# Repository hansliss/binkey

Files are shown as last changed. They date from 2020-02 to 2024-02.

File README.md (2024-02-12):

# binkey
A binary USB keyboard

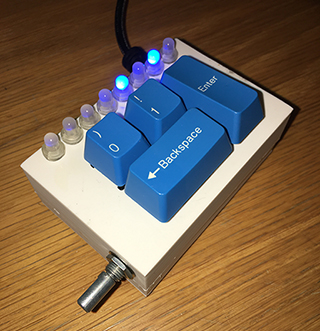
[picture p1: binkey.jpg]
Binkey

Binkey2

You'll need an Arduino Micro or similar, and a nice solution for the USB cable. I cheated and built my own Atmega32U4 PCB and used a scavenged keyboard cable, but you might want to do it differently.

The original box (binkeybox.scad) is designed for Cherry MX keyswitches, with a "0" and "1" key, a vertical straight 2U Enter key and a horizontal straight 2U Backspace key. PLA works fine for this and you probably don't need very high resolution.

Use eight WS2812D-F5 addressable RGB LEDs with the requisite 75Ω resistors on the data lines and 0.1μF capacitors between Vcc and GND (on each LED), and print 16 collars (LEDring.scad) on a resin printer.

I drilled a 7mm hole for the rotary encoder, and I can't be bothered to add this hole to the design.

The new box (binkeybox2.scad) uses only two Cherry keys, a rotary encoder (on the top of the box this time) and a LED strip like Adafruit's 1426.
Notice that the V2 code is tailored for WGRB LEDs. You may need to change that depending on what you use.

For the keyswitches, I used Kailh's hot-swappable sockets, so it's easy to replace the keyswitches without desoldering.

For the rest: Use The Source, Luke!

Oh, and you can find the key codes and modifier codes under "10 Keyboard/Keypad Page (0x07)" in the HID Usage Tables: https://www.usb.org/sites/default/files/documents/hut1_12v2.pdf
For the modifier codes, there's an Excel file that can be used to print out a little lable to glue to the case.

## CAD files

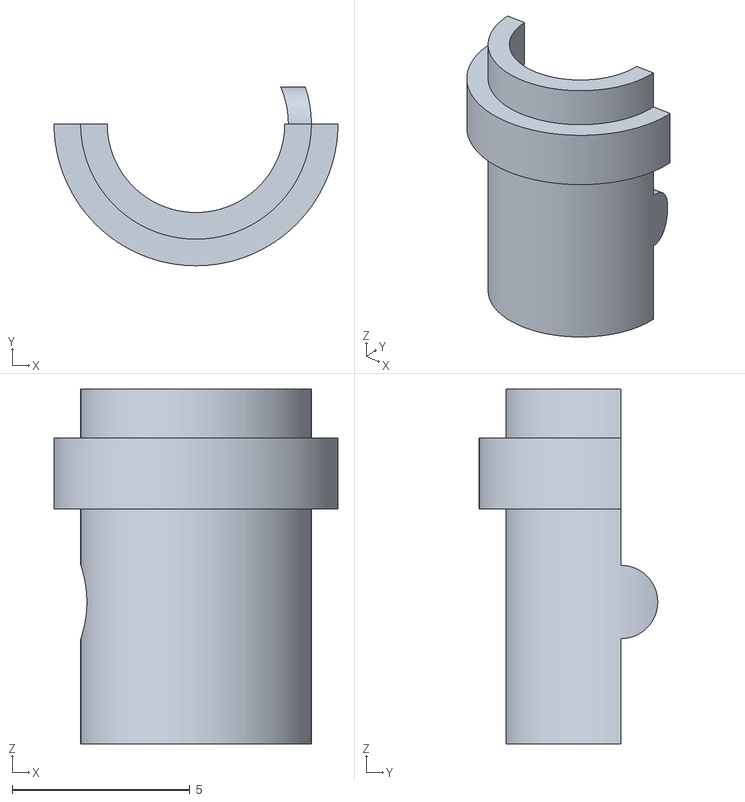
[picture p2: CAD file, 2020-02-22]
LEDring.stl
8.00 x 5.03 x 10.0

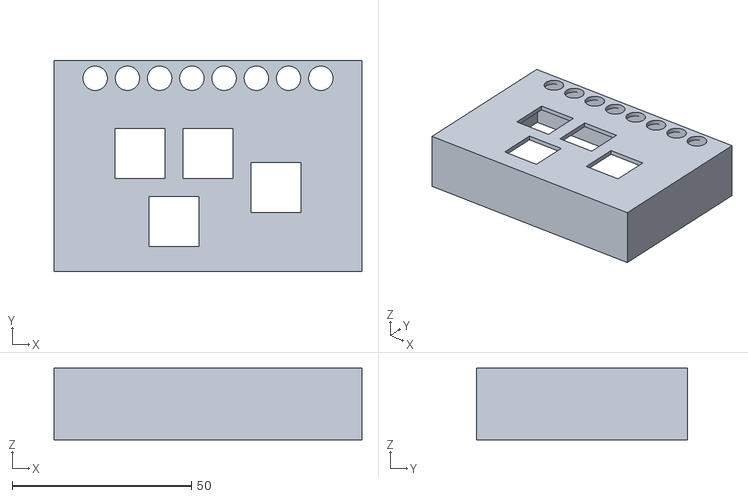
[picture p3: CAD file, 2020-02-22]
BinkeyBoxTop.stl
86.0 x 59.0 x 20.0

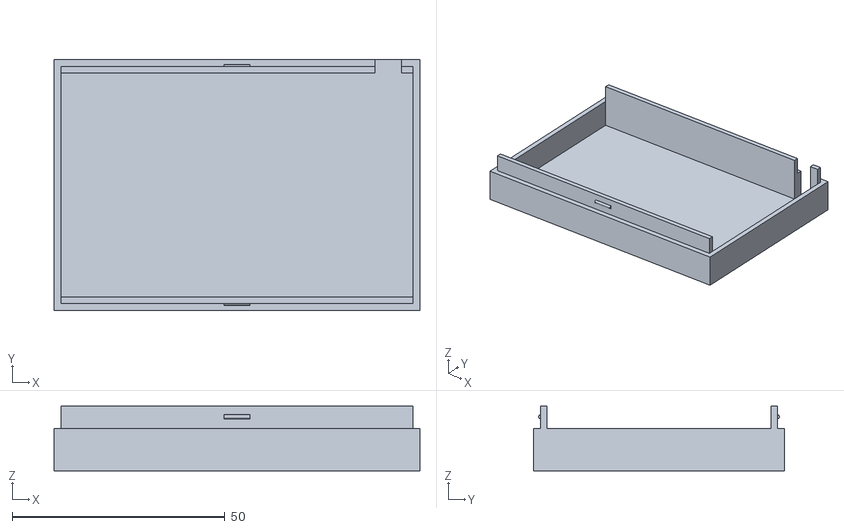
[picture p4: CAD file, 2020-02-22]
BinkeyBoxBottom.stl
86.0 x 59.0 x 15.2

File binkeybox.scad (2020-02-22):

/*
 * A box for the Binkey binary keyboard. You'll need one bottom and one top. Duh.
 * Just uncomment one at a time at the bottom of the file, render and export to STL.
 * 
 * Copyright (c) 2020, Hans Liss
 * 
 * Redistribution and use in source and binary forms, with or without
 * modification, are permitted provided that the following conditions are met:
 * 
 * 1. Redistributions of source code must retain the above copyright notice, this
 *    list of conditions and the following disclaimer.
 * 2. Redistributions in binary form must reproduce the above copyright notice,
 *    this list of conditions and the following disclaimer in the documentation
 *    and/or other materials provided with the distribution.
 * 
 * THIS SOFTWARE IS PROVIDED BY THE COPYRIGHT HOLDERS AND CONTRIBUTORS "AS IS" AND
 * ANY EXPRESS OR IMPLIED WARRANTIES, INCLUDING, BUT NOT LIMITED TO, THE IMPLIED
 * WARRANTIES OF MERCHANTABILITY AND FITNESS FOR A PARTICULAR PURPOSE ARE
 * DISCLAIMED. IN NO EVENT SHALL THE COPYRIGHT OWNER OR CONTRIBUTORS BE LIABLE FOR
 * ANY DIRECT, INDIRECT, INCIDENTAL, SPECIAL, EXEMPLARY, OR CONSEQUENTIAL DAMAGES
 * (INCLUDING, BUT NOT LIMITED TO, PROCUREMENT OF SUBSTITUTE GOODS OR SERVICES;
 * LOSS OF USE, DATA, OR PROFITS; OR BUSINESS INTERRUPTION) HOWEVER CAUSED AND
 * ON ANY THEORY OF LIABILITY, WHETHER IN CONTRACT, STRICT LIABILITY, OR TORT
 * (INCLUDING NEGLIGENCE OR OTHERWISE) ARISING IN ANY WAY OUT OF THE USE OF THIS
 * SOFTWARE, EVEN IF ADVISED OF THE POSSIBILITY OF SUCH DAMAGE.
 */
 
 $fn=256;

capWidthBase=18;
capHeightBase=18;
capWidthEnter=capWidthBase;
capHeightEnter=37;
capWidthBackspace=37;
capHeightBackspace=capHeightBase;
capGap=(capWidthBackspace - 2 * capWidthBase);

key0PosX=capWidthBase / 2;
key0PosY=capHeightBase / 2;
key1PosX=key0PosX + capWidthBase + capGap;
key1PosY=key0PosY;
keyEnterPosX=key1PosX + capWidthBase + capGap;
keyEnterPosY=capHeightEnter / 2;
keyBackspacePosX = capWidthBackspace / 2;
keyBackspacePosY = key0PosY + capHeightBase + capGap;

totKeyCenterDistX = keyEnterPosX - key0PosX;
totKeyCenterDistY = keyBackspacePosY - key0PosY;

edge = 5;
keyOffsetX = 10;
keyOffsetY = edge + 7;

boxWidth=totKeyCenterDistX + capWidthBase + 2 * edge + keyOffsetX + 10;
boxLength=totKeyCenterDistY + capHeightBase + 2 * edge + keyOffsetY;
boxHeight=20;
wallThickness=1.5;


keyHoleWidth=14;
keyHoleLength=14;

notchHeight=4;
botHeight=10;

module top() {
    difference() {
        cube([boxWidth, boxLength, boxHeight], center=true);
        translate([0, 0, -wallThickness/2 - 0.01])
            cube([boxWidth - 2*wallThickness, boxLength - 2*wallThickness, boxHeight - wallThickness + 0.02], center=true);
        translate([edge + keyOffsetX + key0PosX - boxWidth/2, -edge - keyOffsetY - key0PosY + boxLength/2, boxHeight/2 - wallThickness/2])
            cube([keyHoleWidth, keyHoleLength, wallThickness + 0.02], center=true);
        translate([edge + keyOffsetX + key1PosX - boxWidth/2, -edge - keyOffsetY - key1PosY + boxLength/2, boxHeight/2 - wallThickness/2])
            cube([keyHoleWidth, keyHoleLength, wallThickness + 0.02], center=true);
        translate([edge + keyOffsetX + keyEnterPosX - boxWidth/2, -edge - keyOffsetY - keyEnterPosY + boxLength/2, boxHeight/2 - wallThickness/2])
            cube([keyHoleWidth, keyHoleLength, wallThickness + 0.02], center=true);
        translate([edge + keyOffsetX + keyBackspacePosX - boxWidth/2, -edge - keyOffsetY - keyBackspacePosY + boxLength/2, boxHeight/2 - wallThickness/2])
            cube([keyHoleWidth, keyHoleLength, wallThickness + 0.02], center=true);

        for (led = [0 : 1 : 7]) {
            translate([led * 9 + 9/2 + (boxWidth - (8 * 9))/2 - boxWidth/2, -edge + boxLength/2, boxHeight/2 - wallThickness - 0.01])
                cylinder(r = 3.4, h=wallThickness + 0.02);
        } 

        // translate([0, 0, -(boxHeight/2 - wallThickness/2)])
        //    cube([boxWidth + 0.02, boxLength + 0.02, wallThickness + 0.02], center=true);
        translate([-4, boxLength/2 - wallThickness, - (boxHeight/2 - notchHeight)])
            rotate([0, 90, 0])
                cylinder(r=0.75, h=8);
        translate([-4, -(boxLength/2 - wallThickness), - (boxHeight/2 - notchHeight)])
            rotate([0, 90, 0])
                cylinder(r=0.75, h=8);
        translate([boxWidth / 2 - wallThickness - 12/2, boxLength / 2 - wallThickness - 0.01, 12/2 - boxHeight/2 - (botHeight - wallThickness)])
            cube([6.2, 8, 12], center = true);
    }
}

module bottom() {
    difference() {
        union() {
            difference() {
                cube([boxWidth, boxLength, botHeight], center = true);
                translate([0, 0, wallThickness/2 + 0.01])
                    cube([boxWidth - 2 * wallThickness - 0.2, boxLength - 2 * wallThickness - 0.2, botHeight - wallThickness], center = true);
            }
            translate([0, -(boxLength/2 - wallThickness) + wallThickness/2 - 0.2, wallThickness/2])
                cube([boxWidth - 2 * wallThickness - 0.2 + 0.02, wallThickness + 0.2, botHeight - wallThickness], center=true);
            translate([0, -(boxLength/2 - wallThickness) + wallThickness/2 + 0.2, (notchHeight + 2)/2 - 0.01])
                union() {
                    cube([boxWidth - 2 * wallThickness - 0.2 + 0.02, wallThickness, notchHeight + 2 + botHeight - wallThickness], center=true);
                    translate([-6/2, -wallThickness/2, (botHeight - 2) + notchHeight - (notchHeight + 2 + (botHeight - wallThickness))/2])
                        rotate([0, 90, 0])
                            cylinder(r=0.5, h=6);
                }
            translate([0, (boxLength/2 - wallThickness) - wallThickness/2 + 0.2, wallThickness/2])
                cube([boxWidth - 2 * wallThickness - 0.2 + 0.02, wallThickness + 0.2, botHeight - wallThickness], center=true);
            translate([0, (boxLength/2 - wallThickness) - wallThickness/2  - 0.2, (notchHeight + 2)/2 - 0.01])
                union() {
                    cube([boxWidth - 2*wallThickness -0.2 + 0.02, wallThickness, notchHeight + 2 + botHeight - wallThickness], center=true);
                    translate([-6/2, wallThickness/2, (botHeight - 2) + notchHeight - (notchHeight + 2 + (botHeight - wallThickness))/2])
                        rotate([0, 90, 0])
                            cylinder(r=0.5, h=6);
                }
        }
        translate([boxWidth / 2 - wallThickness - 12/2, boxLength / 2 - wallThickness - 0.01, wallThickness + 12/2 - botHeight/2])
            cube([6.2, 8, 12], center = true);
        // Need to remove the top of the cable slot
        translate([boxWidth / 2 - wallThickness - 12/2, boxLength / 2 - wallThickness - 0.01, wallThickness + 12 + 12/2 - botHeight/2 - 0.01])
            cube([6.2, 8, 12], center = true);
   }
}


//translate([0, 0, 30])
//    top();
bottom();

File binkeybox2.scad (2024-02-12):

$fn=256;

capWidthBase=18;
capHeightBase=18;

keyHoleWidth=14.5;
keyHoleLength=14.5;

boxWidth=80;
boxDepth=40;
boxTopRawHeight=30;

module baseBox() {
        rotate([10, 0, 0])
        difference() {
            union() {
                cube([boxWidth, boxDepth, boxTopRawHeight], center=true);
                translate([-boxWidth/2, boxDepth/2, 0])
                    rotate([0, 90, 0])
                        cylinder(r=boxTopRawHeight/2, h=boxWidth);
                translate([-boxWidth/2, -boxDepth/2, boxTopRawHeight/2 - boxTopRawHeight/4])
                    rotate([0, 90, 0])
                        cylinder(r=boxTopRawHeight/4, h=boxWidth);
            }
            translate([-10, boxDepth/2 - 5, boxTopRawHeight/2 - 1 - 0.6])
                cube([50.5, 5.5, 2], center=true);
            translate([-22, -5, boxTopRawHeight / 2 + 5])
                cube([keyHoleWidth, keyHoleLength, boxTopRawHeight], center=true);
            translate([-22 + capWidthBase + 5, -5, boxTopRawHeight / 2 + 5])
                cube([keyHoleWidth, keyHoleLength, boxTopRawHeight], center=true);
            translate([28, 12, boxTopRawHeight/2 - 5])
                cylinder(r=3.65, h=10);
            union() {
                translate([0, 0, -0.751])
                    cube([boxWidth-3, boxDepth - 3, boxTopRawHeight - 1.5], center=true);
                translate([-(boxWidth-3)/2, boxDepth/2, 0])
                    rotate([0, 90, 0])
                        cylinder(r=boxTopRawHeight/2 - 1.5, h=boxWidth-3);
            }
    }
}

module top() {
    difference() {
        intersection() {
            baseBox();
            translate([0, 0, boxTopRawHeight])
                cube([boxWidth + 1, boxDepth + boxTopRawHeight, boxTopRawHeight * 2], center=true);
        }
        translate([1/2 + boxWidth/2 - 1.5 - 0.01, 0, 5 / 2 - 0.01])
            union() {
                cube([1, 5.2, 5.2], center=true);
                translate([0.2, 0, 1.5])
                    sphere(r=0.7);
            }
        translate([-(1/2 + boxWidth/2 - 1.5) + 0.01, 0, 5 / 2 - 0.01])
            union() {
                cube([1, 5.2, 5.2], center=true);
                translate([-0.2, 0, 1.5])
                    sphere(r=0.7);
            }
        translate([boxWidth / 2 - 7, boxDepth - 5, 0])
            rotate([90, 0, 0])
                cylinder(r=1.9, h=10);
    }
}

module bottom() {
    difference() {
        union() {
            intersection() {
                baseBox();
                translate([0, 0, -(boxDepth/2)*tan(10) / 2])
                    cube([boxWidth + 1, boxDepth + boxTopRawHeight, (boxDepth/2)*tan(10)], center=true);
            }
            translate([0, (boxTopRawHeight - 4) / 4, 1.5 / 2 - (boxDepth/2)*tan(10) + 0.15])
                cube([boxWidth - 3 + 0.02, boxDepth - 3 + boxTopRawHeight / 2 - 2 + 0.02, (boxDepth/2)*tan(10) / 2], center = true);
            translate([1/2 + boxWidth/2 - 1.5, 0, 5 / 2 - 0.01])
                union() {
                    cube([1, 5, 5], center=true);
                    translate([0.2, 0, 1.5])
                        sphere(r=0.7);
                }
            translate([-(1/2 + boxWidth/2 - 1.5), 0, 5 / 2 - 0.01])
                union() {
                    cube([1, 5, 5], center=true);
                    translate([-0.2, 0, 1.5])
                        sphere(r=0.7);
                }
        }
        translate([boxWidth / 2 - 7, boxDepth - 5, 0])
            rotate([90, 0, 0])
                cylinder(r=1.9, h=10);
    }
}

//translate([0, 0, 10])
rotate([170, 0, 0])
    top();

//bottom();

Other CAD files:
LEDring.scad

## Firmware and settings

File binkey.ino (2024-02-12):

/*
 * Binkey, a Mini binary keyboard
 * Use an Arduino Micro or similar for this.
 * Needs the Adafruit NeoPixel library, and Paul Stoffregen's Encoder library
 * Credit for the HID code belongs to Konstantin Schauwecker, and "qwelyt" - https://github.com/qwelyt/Keyboard/tree/master/Code/ModuleA/V2/ModuleA
 * 
 * Copyright (c) 2020, Hans Liss
 * 
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
 * THIS SOFTWARE IS PROVIDED BY THE COPYRIGHT HOLDERS AND CONTRIBUTORS "AS IS" AND
 * ANY EXPRESS OR IMPLIED WARRANTIES, INCLUDING, BUT NOT LIMITED TO, THE IMPLIED
 * WARRANTIES OF MERCHANTABILITY AND FITNESS FOR A PARTICULAR PURPOSE ARE
 * DISCLAIMED. IN NO EVENT SHALL THE COPYRIGHT OWNER OR CONTRIBUTORS BE LIABLE FOR
 * ANY DIRECT, INDIRECT, INCIDENTAL, SPECIAL, EXEMPLARY, OR CONSEQUENTIAL DAMAGES
 * (INCLUDING, BUT NOT LIMITED TO, PROCUREMENT OF SUBSTITUTE GOODS OR SERVICES;
 * LOSS OF USE, DATA, OR PROFITS; OR BUSINESS INTERRUPTION) HOWEVER CAUSED AND
 * ON ANY THEORY OF LIABILITY, WHETHER IN CONTRACT, STRICT LIABILITY, OR TORT
 * (INCLUDING NEGLIGENCE OR OTHERWISE) ARISING IN ANY WAY OUT OF THE USE OF THIS
 * SOFTWARE, EVEN IF ADVISED OF THE POSSIBILITY OF SUCH DAMAGE.
 */

#include <Adafruit_NeoPixel.h>
#include <Encoder.h>

#include "KeyboardLib.h"

#define VERSION 2

#define LED_PIN 13
#define LED_COUNT 8

#if VERSION == 1
  Adafruit_NeoPixel strip(LED_COUNT, LED_PIN, NEO_RGB + NEO_KHZ800);
#else
  Adafruit_NeoPixel strip(LED_COUNT, LED_PIN, NEO_GRBW + NEO_KHZ800);
#endif

long vals[LED_COUNT];
long oldvals[LED_COUNT];

#define BTN0_PIN 11        // buttons included on shield
#define BTN1_PIN 3        // these are Arduino pin numbers
#define BTNEnter_PIN 6
#define BTNBS_PIN 9
#define BTNEnc_PIN 2

#define ENCPin1 1
#define ENCPin2 0

#define BTN0 0
#define BTN1 1
#define BTNEnter 2
#define BTNBS 3
#define BTNEnc 4

const int buttons[] = { BTN0_PIN, BTN1_PIN, BTNEnter_PIN, BTNBS_PIN, BTNEnc_PIN};

Encoder knob(ENCPin1, ENCPin2);

// See below; we can't handle more than 6 simultaneous keys here at the moment, since
// we are always sending a single report. It's perfectly possible to update this to handle
// arbitrarily long strings. I just don't want to.
// Or maybe it will work anyway, actually. I haven't tried it. Whatever.
#define REGCOUNT 7

int reg[REGCOUNT];

#define COLOR_KEYCODE 0.6
#define COLOR_META 0.25
#define COLOR_XMIT 0

#define MAXVAL 1024

void setup() {
  strip.begin();           // INITIALIZE NeoPixel strip object (REQUIRED)
  strip.show();            // Turn OFF all pixels ASAP
  strip.setBrightness(100); // Set BRIGHTNESS much lower than max (255) since these LEDS are Mighty Powderful.
  initButtons();
  initKeyboard();
  for (int i = 0; i < REGCOUNT; i++) {
    reg[i] = 0;
  }
  showReg(reg[0], COLOR_KEYCODE);
  /*
  Serial.begin(9600);
  while(!Serial) {
    ;
  }
  */
}

void showReg(int reg, float color) {
  for (int i=0; i<8; i++) {
    // Make the leds show a dim color even on 0, so we know which register
    // is active.
    vals[i] = (reg & (1 << i))?MAXVAL:MAXVAL/3;
  }
  setLEDs(vals, color);
}

void loop() {
  boolean updateLEDs=false;
#if VERSION == 2
  static boolean lastButtonState = false;
#endif
  // The current register
  static int regind = 0;
  // We need an offset for the knob value, since we want to be able to
  // reset all the registers and switch to the first keycode register - 
  // but we can't affect the current knob value. Thus, we use the offset
  // to register the current knob value upon reset.
  static int regoffs = 0;
  static long idlemillis = 0;
  static boolean idle = false;
  boolean didsomething = false;
  long knobValue;
  static long oldKnobValue=(knob.read() >> 2);
  readButtons();
  // Shift in a "1"
  if (hasButtonPressEvent(BTN0)) {
    reg[regind] = (reg[regind] << 1) & 0xFF;
    updateLEDs=true;
  }
  // Shift in a "0"
  if (hasButtonPressEvent(BTN1)) {
    reg[regind] = ((reg[regind] << 1) | 1) & 0xFF;
    updateLEDs=true;
  }
  #if VERSION == 1
  // Shift right
  if (hasButtonPressEvent(BTNBS)) {
    reg[regind] >>= 1;
    updateLEDs=true;
  }
  // Encoder button resets all the registers and switches to the first
  // keycode register.
  if (hasButtonPressEvent(BTNEnc)) {
    for (int i=0; i<REGCOUNT; i++) {
      reg[i] = 0;
    }
    updateLEDs = true;
    regind = 0;
    regoffs = oldKnobValue;
  }
  #endif
  // Read the knob and switch register as requested
  knobValue=(knob.read() >> 2);
  if (knobValue != oldKnobValue) {
    oldKnobValue=knobValue;
    regind = knobValue - regoffs;
    while (regind < 0) {
      regind += REGCOUNT;
    }
    regind = regind % REGCOUNT;
    updateLEDs = true;
  }

  if (idle) {
    runningLights();
  }
  // If anything has changed, update the LEDs
  if (updateLEDs) {
    idle = false;
    showReg(reg[regind], ((regind == REGCOUNT-1)?COLOR_META:COLOR_KEYCODE));
    didsomething = true;
  }
  // On Enter, send - first the Modifiers' Down events, then the Key Down event,
  // then wait a bit and then do the Up events in reverse order.
#if VERSION == 1
  if (hasButtonPressEvent(BTNEnter)) {
    showReg(reg[0], COLOR_XMIT);
    sendCode(reg, 0, reg[REGCOUNT-1]);
    sendCode(reg, REGCOUNT-1, reg[REGCOUNT-1]);
    delay(20);
    sendCode(reg, 0, reg[REGCOUNT-1]);
    sendCode(reg, 0, 0);
    showReg(reg[regind], ((regind == REGCOUNT-1)?COLOR_META:COLOR_KEYCODE));
    didsomething = true;
  }
#else
  if (isButtonPressed(BTNEnc) && !lastButtonState) {
    sendCode(reg, 0, reg[REGCOUNT-1]);
    sendCode(reg, REGCOUNT-1, reg[REGCOUNT-1]);
    lastButtonState = true;
    didsomething = true;
  }
  if (!isButtonPressed(BTNEnc) && lastButtonState) {
    sendCode(reg, 0, 0);
    sendCode(reg, 0, 0);
    lastButtonState = false;
    didsomething = true;
  }
#endif
  if (!didsomething) {
    bool hasvalue = false;
    for (int i=0; i<REGCOUNT; i++) {
      if (reg[i] != 0) {
        hasvalue = true;
      }
    }
    if (!hasvalue) {
      if (idlemillis == 0) {
        idlemillis = millis();
      } else {
        if (millis() - idlemillis > 60000) {
          idle = true;
        }
      }
    }
  } else {
    idlemillis = 0;
  }
  if (!idle) {
    delay(10);
  }
}

#pragma region "LED code"

void setLEDs(long *vals, float color) {
  int i;
  for (i=0; i < LED_COUNT; i++) {
    float H = color;//(float)vals[i]/MAXVAL;
    float V = (float)vals[i]/MAXVAL;
    float S = 1;
    int R, G, B;
    hsv2rgb(H,S,V,&R,&G,&B);
    uint32_t color = strip.Color(R, G, B);
    strip.setPixelColor(i, strip.gamma32(color));
  }
  strip.show();
}

void clearLEDs() {
  for (int i=0; i < LED_COUNT; i++) {  
    strip.setPixelColor(i, 0);
  }
  strip.show();
}

// Convert hue/saturation/brightness values [0,1] to R/G/B values [0,255]
void hsv2rgb(float H,float S,float V,int *R,int *G,int *B)
{
  int i;
  float f,p,q,t;
  H = H*6;
  if (H>=6)
    H-=6;
  i=H;
  f=H-(float)i;
  p=V*(1.0-S);
  q=V*(1.0-(S*f));
  t=V*(1.0-(S*(1.0-f)));

  switch(i)
    {
    case 0: (*R)=V*255; (*G)=t*255; (*B)=p*255; break;
    case 1: (*R)=q*255; (*G)=V*255; (*B)=p*255; break;
    case 2: (*R)=p*255; (*G)=V*255; (*B)=t*255; break;
    case 3: (*R)=p*255; (*G)=q*255; (*B)=V*255; break;
    case 4: (*R)=t*255; (*G)=p*255; (*B)=V*255; break;
    case 5: (*R)=V*255; (*G)=p*255; (*B)=q*255; break;
    }
}

#pragma endregion "LED code"

#pragma region "Button handling code"

#define NBUTTONS (sizeof(buttons)/sizeof(int))
int buttonState[NBUTTONS];
boolean isButtonRead[NBUTTONS];
int lastButtonState[NBUTTONS];
int lastDebounceTime[NBUTTONS];
unsigned long debounceDelay = 10;    // the debounce time; increase if the output flickers

void readButton(int bNo) 
{
  int reading = digitalRead(buttons[bNo]);
  // If the switch changed, due to noise or pressing:
  if (reading != lastButtonState[bNo]) 
  {
    // reset the debouncing timer
    lastDebounceTime[bNo] = millis();
  }

  if ((millis() - lastDebounceTime[bNo]) > debounceDelay) 
  {
    // whatever the reading is at, it's been there for longer than the debounce
    // delay, so take it as the actual current state:

    // if the button state has changed:
    if (reading != buttonState[bNo]) 
    {
      buttonState[bNo] = reading;
      isButtonRead[bNo] = false;
    }
  }
  lastButtonState[bNo] = reading;
}

void readButtons() {
  for (int i = 0; i < NBUTTONS; i++) {
    readButton(i);
  }
}

void initButtons() {
  for (int i = 0; i < NBUTTONS; i++) {
    pinMode(buttons[i], INPUT_PULLUP);
    buttonState[i] = HIGH;
    lastButtonState[i] = HIGH;
    isButtonRead[i] = true;
  }
}

boolean hasButtonPressEvent(int bNo) {
  if (buttonState[bNo] == LOW && !isButtonRead[bNo]) {
    isButtonRead[bNo] = true;
    return true;
  }
  else {
    return false;
  }
}

boolean isButtonPressed(int bNo) {
  return buttonState[bNo] == LOW;
}

#pragma endregion "Button handling code"

#pragma region "HID code"

const byte keyLimit = 6;
byte keyPlace = 0;
uint8_t keyBuf[keyLimit];
uint8_t meta = 0x0;
void addKeyToBuffer(uint8_t key) {
  keyBuf[keyPlace++] = key;
}

void sendCode(int code[], int numkeys, int metaIn) {
  resetKeys();
  for (int i=0; i < numkeys; i++) {
    addKeyToBuffer(code[i]);
  }
  meta = metaIn;
  sendBuffer(meta, keyBuf);
}

void sendBuffer(uint8_t meta, uint8_t keyBuf[]) {
  sendKeyBuffer(meta, keyBuf);
  resetKeys();
}

void resetKeys() {
  for (byte b = 0; b < keyLimit; ++b) {
    keyBuf[b] = 0x0;
  }
  keyPlace = 0;
  meta = 0x0;
}

#pragma endregion "HID code"

#pragma region "Light show"

#define FADEIN_FACTOR (MAXVAL / 10)
#define FADEIN_FAST_DELAY 10
#define FADEIN_SLOW_DELAY 20
#define CMODE_SPECTRUM_SAT 0

#define FADEIN(v, max) ((v) + min(FADEIN_FACTOR, max - (v)))
#define FADEOUT(v) (29 * (v) / 30)

float correction_R = 0.5;
float correction_G = 0.5;
float correction_B = 0.5;

float satVal=0;
float satValstep=0.0005;

uint32_t valToColor_Sat(long val) {
  float H = (float)val/MAXVAL;
  float V = 1; //(float)val/MAXVAL;
  float S = satVal;
  int R, G, B;
  hsv2rgb(H,S,V,&R,&G,&B);
  satVal += satValstep;
  if (((satValstep > 0) && (satVal >= 1)) ||
      ((satValstep < 0) && (satVal <= 0))) {
    satValstep = -satValstep;
  }
  return strip.Color(correction_R * (float)R, correction_G * (float)G, correction_B * (float)B);
}

void setCandles(long *vals) {
  int i;
  for (i=0; i < LED_COUNT; i++) {
    if (vals[i] != oldvals[i]) {
      strip.setPixelColor(i, strip.gamma32(valToColor_Sat(vals[i])));
      oldvals[i] = vals[i];
    }
  }
  strip.show();
}

void runningLights() {
  static int rl_runDir=1;
  static int rl_pos=0;
  static int rl_del=FADEIN_FAST_DELAY;
  static int rl_count=rl_del;
  int i;
#ifdef DEBUG
  if (trace) {
    while (!Serial) {
      ;
    }
    Serial.println("runningLights: rl_runDir=" + String(rl_runDir) + ", rl_pos=" + String(rl_pos) + ", rl_del=" + String(rl_del) + ", rl_count=" + String(rl_count));
  }
#endif
  if (rl_runDir == 1 && rl_pos >= (LED_COUNT - 1)) {
    rl_runDir = -1;
    rl_pos = LED_COUNT - 1; // Just to be safe
  } else if (rl_runDir == -1 && (rl_pos <= 0)) {
    rl_runDir = 1;
    rl_pos = 0; // Just to be safe
  }
  if (--rl_count == 0) {
    rl_count = rl_del;
    vals[rl_pos] = MAXVAL;
    rl_pos += rl_runDir;
  } else {
    if (vals[rl_pos] < MAXVAL) {
      vals[rl_pos] = FADEIN(vals[rl_pos], MAXVAL);
    }
  }
  
  for (i=0; i<LED_COUNT; i++) {
    if (i != rl_pos && vals[i] > 0) {
      vals[i] = FADEOUT(vals[i]);
    }
  }
  setCandles(vals);
  delay(340/LED_COUNT);
}

#pragma endregion "Light show"

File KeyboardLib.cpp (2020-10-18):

#include <HID.h>
#include <string.h>
#include "KeyboardLib.h"

const uint8_t REPORT_ID = 0x02;
/*
static const uint8_t hidReportDescriptor[] PROGMEM = {

  //  Keyboard
  0x05, 0x01,                    // USAGE_PAGE (Generic Desktop)
  0x09, 0x06,                    // USAGE (Keyboard)
  0xa1, 0x01,                    // COLLECTION (Application)
  0x85, REPORT_ID,               //   REPORT_ID (2)
  0x05, 0x07,                    //   USAGE_PAGE (Keyboard)

  0x19, 0xe0,                    //   USAGE_MINIMUM (Keyboard LeftControl)
  0x29, 0xe7,                    //   USAGE_MAXIMUM (Keyboard RightGUI)
  0x15, 0x00,                    //   LOGICAL_MINIMUM (0)
  0x25, 0x01,                    //   LOGICAL_MAXIMUM (1)
  0x75, 0x01,                    //   REPORT_SIZE (1)

  0x95, 0x08,                      //   REPORT_COUNT (8)
  0x81, 0x02,                    //   INPUT (Data,Var,Abs)
  0x95, 0x01,                    //   REPORT_COUNT (1)
  0x75, 0x08,                    //   REPORT_SIZE (8)
  0x81, 0x03,                    //   INPUT (Cnst,Var,Abs)

  0x95, 0x06,                      //   REPORT_COUNT (6)
  0x75, 0x08,                    //   REPORT_SIZE (8)
  0x15, 0x00,                    //   LOGICAL_MINIMUM (0)
  0x25, 0x65,                    //   LOGICAL_MAXIMUM (101)
  0x05, 0x07,                    //   USAGE_PAGE (Keyboard)

  0x19, 0x00,                      //   USAGE_MINIMUM (Reserved (no event indicated))
  0x29, 0x65,                    //   USAGE_MAXIMUM (Keyboard Application)
  0x81, 0x00,                    //   INPUT (Data,Ary,Abs)
  0xc0,                          // END_COLLECTION

};
*/
static const uint8_t hidReportDescriptor[] PROGMEM = {

  //  Keyboard
  0x05, 0x01,                    // USAGE_PAGE (Generic Desktop)
  0x09, 0x06,                    // USAGE (Keyboard)
  0xa1, 0x01,                    // COLLECTION (Application)
  0x85, REPORT_ID,               //   REPORT_ID (2)
  0x05, 0x07,                    //   USAGE_PAGE (Keyboard)

// Modifiers
  0x19, 0xe0,                    //   USAGE_MINIMUM (Keyboard LeftControl)
  0x29, 0xe7,                    //   USAGE_MAXIMUM (Keyboard RightGUI)
  0x15, 0x00,                    //   LOGICAL_MINIMUM (0)
  0x25, 0x01,                    //   LOGICAL_MAXIMUM (1)
  0x75, 0x01,                    //   REPORT_SIZE (1)
  0x95, 0x08,                    //   REPORT_COUNT (8)
  0x81, 0x02,                    //   INPUT (Data,Var,Abs)

// Reserved byte
  0x95, 0x01,                    //   REPORT_COUNT (1)
  0x75, 0x08,                    //   REPORT_SIZE (8)
  0x81, 0x03,                    //   INPUT (Cnst,Var,Abs)

// Keycodes
  0x95, 0x06,                    //   REPORT_COUNT (6)
  0x75, 0x08,                    //   REPORT_SIZE (8)
  0x15, 0x00,                    //   LOGICAL_MINIMUM (0)
  0x25, 0xff,                    //   LOGICAL_MAXIMUM (df)
  0x05, 0x07,                    //   USAGE_PAGE (Keyboard)
  0x19, 0x00,                    //   USAGE_MINIMUM (Reserved (no event indicated))
  0x29, 0xff,                    //   USAGE_MAXIMUM (Keyboard Application)
  0x81, 0x00,                    //   INPUT (Data,Ary,Abs)
  
  0xc0,                          // END_COLLECTION

};
/*
char ReportDescriptor[] = {
0x05, 0x01,                         // Usage Page (Generic Desktop)
0x09, 0x06,                         // Usage (Keyboard)
0xA1, 0x01,                         // Collection (Application)
0x85, REPORT_ID,               //   REPORT_ID (2)
0x05, 0x07,                         //     Usage Page (Key Codes)
0x19, 0xe0,                         //     Usage Minimum (224)
0x29, 0xe7,                         //     Usage Maximum (231)
0x15, 0x00,                         //     Logical Minimum (0)
0x25, 0x01,                         //     Logical Maximum (1)
0x75, 0x01,                         //     Report Size (1)
0x95, 0x08,                         //     Report Count (8)
0x81, 0x02,                         //     Input (Data, Variable, Absolute)

0x95, 0x01,                         //     Report Count (1)
0x75, 0x08,                         //     Report Size (8)
0x81, 0x01,                         //     Input (Constant) reserved byte(1)

0x95, 0x05,                         //     Report Count (5)
0x75, 0x01,                         //     Report Size (1)
0x05, 0x08,                         //     Usage Page (Page# for LEDs)
0x19, 0x01,                         //     Usage Minimum (1)
0x29, 0x05,                         //     Usage Maximum (5)
0x91, 0x02,                         //     Output (Data, Variable, Absolute), Led report
0x95, 0x01,                         //     Report Count (1)
0x75, 0x03,                         //     Report Size (3)
0x91, 0x01,                         //     Output (Data, Variable, Absolute), Led report padding

0x95, 0x06,                         //     Report Count (6)
0x75, 0x08,                         //     Report Size (8)
0x15, 0x00,                         //     Logical Minimum (0)
0x25, 0x65,                         //     Logical Maximum (101)
0x05, 0x07,                         //     Usage Page (Key codes)
0x19, 0x00,                         //     Usage Minimum (0)
0x29, 0x65,                         //     Usage Maximum (101)
0x81, 0x00,                         //     Input (Data, Array) Key array(6 bytes)


0x09, 0x05,                         //     Usage (Vendor Defined)
0x15, 0x00,                         //     Logical Minimum (0)
0x26, 0xFF, 0x00,                   //     Logical Maximum (255)
0x75, 0x08,                         //     Report Count (2)
0x95, 0x02,                         //     Report Size (8 bit)
0xB1, 0x02,                         //     Feature (Data, Variable, Absolute)

0xC0                                // End Collection (Application)
};
*/
typedef struct
{
  uint8_t modifiers;
  uint8_t reserved;
  uint8_t keys[6];
} KeyReport;

void initKeyboard() {
  static HIDSubDescriptor node(hidReportDescriptor, sizeof(hidReportDescriptor));
  //static HIDSubDescriptor node(ReportDescriptor, sizeof(ReportDescriptor));
  HID().AppendDescriptor(&node);
}

void sendKeyBuffer(uint8_t meta, uint8_t keys[]) {
  KeyReport report;

  report.modifiers = meta;
  
  for(byte b=0; b<6; ++b){
    report.keys[b] = keys[b];
  }

  Serial.println();
  Serial.print(report.modifiers);
  for(byte b=0; b<6; ++b){
    Serial.print(" ");
    Serial.print(report.keys[b]);
  }
  Serial.println();

  HID().SendReport(REPORT_ID, &report, sizeof(report));
}

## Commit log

2020-02-22 Initial import
    [BinkeyBoxBottom.stl, BinkeyBoxTop.stl, LEDring.scad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]
2020-02-22 Tested and fixed support for full six-key report, including colour scheme. Switched back to single-key.
    [binkey.ino]
2020-02-22 Changed colors so all keycode registers are now blue. Only the meta register is different. Updated to 6 keycode slots (plus one for meta), and made sure they are sent in a single report.
2020-02-23 Simplified the HID code a little more, and fixed a bug preventing the meta key events from working.
    [binkey.ino]
2020-10-18 Added a 1 minute idle timeout, turning off the LEDs if *all* registers have been zero and no buttons pressed for one minute.
2024-02-10 New version, without Enter and Backspace keys, with GRBW LED strip and with a new case.
    [Modlabel.xlsx, binkeybox2.scad]
2024-02-12 Added hardware version #define to sketch. Changed V2 behaviour to keep button state while the knob is pushed. Added RGB light show. Moved encoder hole slightly to the right.
    [binkeybox2.scad]
